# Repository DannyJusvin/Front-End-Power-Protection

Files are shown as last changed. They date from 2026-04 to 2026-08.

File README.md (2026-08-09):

# 🔌 Front-End Power Protection System

### Discrete 12V DC Safeguard with Soft-Start Logic

---

## 📌 Overview

This project presents a **discrete front-end power protection circuit** designed for 12V DC systems. It protects sensitive electronics from unsafe input conditions using a **P-channel MOSFET-based high-side topology**.

The design integrates:

* Over-voltage protection (OVP) with hysteresis
* Reverse polarity protection
* Controlled soft-start to mitigate inrush current

The circuit was designed, simulated, and validated in **LTspice**, and documented with a complete engineering workflow.

---

## 🚀 Design Evolution

The project evolved through three implementation stages:

1. **LTspice — Circuit Design & Verification**
   - Circuit behavior and protection functions were developed and validated through simulation.

2. **KiCad — THT Prototype Schematic**
   - The validated circuit was documented as a through-hole-oriented schematic for the initial implementation.

3. **Altium Designer — SMT PCB Implementation**
   - The design was transitioned to surface-mount components and implemented as a two-layer PCB.
   - Component libraries and footprints were configured, followed by component placement, manual routing, ground-plane implementation, and DRC verification.
   - PCB 3D models were integrated and aligned for board-level 3D inspection and design verification.
   - Gerber, NC Drill, and Pick-and-Place manufacturing outputs were generated.

The electrical functionality was retained during the transition, while the implementation evolved from a simulation/prototype-oriented design toward a more compact, manufacturing-oriented PCB.

---

## 🎯 Key Features

* ⚡ **Over-Voltage Protection (OVP)**

  * Trip: ~13.9 V
  * Release: ~13.3 V (hysteresis ≈ 0.6 V)

* 🔄 **Reverse Polarity Protection**

  * Implemented using a high-current Schottky diode (MBR745)

* ⏱️ **Soft-Start Control**

  * ~10–13 ms controlled ramp
  * Reduces inrush current stress

* ⚡ **Fast Protection Response**

  * ~1.6 µs detection and cutoff (comparator + gate drive)

---

## 🧠 Design Highlights

* Discrete implementation (no integrated protection ICs)
* Demonstrates:

  * Comparator-based decision making
  * Positive feedback (hysteresis)
  * MOSFET gate control dynamics
  * Real-world non-idealities (Zener knee region, MOSFET capacitances)

---

## 🧩 System Architecture

* Input Protection (Schottky diode)
* Power Switching (PMOS – IRF4905)
* Analog Control (LM393 comparator + reference + hysteresis)
* Gate Drive & Soft-Start (PNP + RC network + clamp)

---

## 📊 Performance Summary

| Parameter | Value |
| --- | --- |
| Nominal Input | 12 V |
| OVP Trip | ~13.9 V |
| OVP Release | ~13.3 V |
| Soft-Start Time | ~10–13 ms |
| Response Time | ~1.6 µs |
| Efficiency | ~96% |
| Practical Current | ~2–3 A (continuous, no heatsink) |

---

## 🧪 Simulation & Validation

* LTspice transient simulations
* Tested scenarios:

  * Normal startup
  * Over-voltage event
  * Load variation (10Ω, 2Ω, 1Ω)
  * Reverse polarity

---

## ⚠️ Limitations

* No over-current protection (OCP)
* No under-voltage lockout (UVLO)
* Diode voltage drop reduces efficiency
* Zener-based reference has limited accuracy

---

## 🚀 Future Improvements

* Add current sensing (INA180 / shunt-based OCP)
* Replace Zener with precision reference (TL431)
* Use ideal diode MOSFET for lower loss
* Add UVLO and thermal protection

---

## 📁 Repository Contents

* Project Documentation
* Project Log
* Block Diagram
* BOM — THT and SMT component lists
* LTspice simulation files and waveform results
* KiCad prototype schematic — THT implementation
* Altium Designer schematic and PCB — SMT implementation
* PCB renders and layout images
* Gerber manufacturing files
* NC Drill files
* Pick-and-Place files

---

## 🛠 Tools Used

* LTspice (Simulation)
* KiCad (Schematic)
* Altium (Schematic & PCB Design)
* draw.io (Block Diagram)

---

## 💡 Author Note

This project was developed to deeply understand analog power protection design, including transient behavior, feedback systems, and real-world component limitations, while also gaining hands-on experience with LTspice simulation, KiCad schematic development, Altium Designer PCB design, component libraries, design-rule verification, and manufacturing preparation.

---

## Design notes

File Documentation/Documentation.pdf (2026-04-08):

# FRONT-END POWER PROTECTION SYSTEM

## Discrete 12V DC Safeguard with Soft-Start Logic

### TABLE OF CONTENTS

- Abstract - Problem Statement - Project Overview - Design Objectives - System Architecture - Circuit Operation - Circuit Schematic - Tools & Technologies - Design Calculations & Engineering Decisions - Component Selection & Justification - Bill of Materials (BoM) - Simulation Setup - Performance Analysis - Real-World Consideration - Limitations - Future Improvements - Design Evolution - Conclusion - References

# 1. Abstract

An LTspice-validated 12V DC front-end protection circuit designed to shield sensitive electronics using a discrete P-channel MOSFET topology. The system integrates 13.9V over-voltage protection with hysteresis, reverse polarity safety, and a controlled 10–13 ms soft-start to mitigate inrush current. By avoiding integrated IC solutions, the project demonstrates a deep-dive into the fundamental trade-offs of analog power management, transient response, and circuit stability.

# 2. Problem Statement

Modern 12V electronic systems—including embedded controllers, communication devices, and analog subsystems—typically operate within a narrow voltage range (~11–13.2V). Despite being powered by regulated DC supplies, these systems remain highly vulnerable to several real-world electrical faults:

- Over-Voltage Conditions: Triggered by regulator failure, supply overshoot, or transient spikes

that exceed safe operating limits.

- Reverse Polarity Connection: Accidental incorrect supply connections during installation or

maintenance.

- High Inrush Current: Rapid charging of decoupling capacitors during startup, which stresses

both the power path and the load components.

Even short-duration over-voltage events can exceed the absolute maximum ratings (typically ~15V) of downstream ICs, leading to immediate degradation or permanent failure. Furthermore, while integrated protection ICs (e.g., hot-swap controllers) are available, they often act as "black boxes," abstracting away the underlying analog behaviors and transient responses.

This project addresses the need for a transparent, discrete protection solution that provides robust fault protection while exposing the internal design trade-offs, non-ideal component behaviors, and real-world stability challenges inherent in power electronics.

# 3. Project Overview

This project presents the design and simulation of a 12V DC power protection circuit intended for low-power electronic systems. The circuit acts as a front-end protection module placed between a DC power source and a sensitive load, ensuring safe and controlled power delivery under both normal and fault conditions.

The design integrates multiple protection features into a single discrete implementation:

- Reverse Polarity Protection: Prevents damage from incorrect supply connections.
- Over-Voltage Protection (OVP): Features a cutoff threshold of approximately 13.9V.
- Hysteresis (~0.6V): Ensures stable switching and prevents chatter.
- Soft-Start Control (~10–13ms): Limits inrush current during startup and recovery.
- High-Speed Gate-Drive: Ensures rapid MOSFET turn-off during fault conditions.

The circuit is built using a high-side P-channel MOSFET switching topology, controlled by a comparator-based decision stage and supported by analog feedback networks.

The primary objective of this project is not only functional implementation but also to explore real-world analog design challenges such as non-ideal component behavior, transient response, stability, thermal considerations, and protection trade-offs.

The design was developed and validated entirely through LTspice simulation, with extensive testing under multiple conditions including load variation, over-voltage events, and reverse polarity scenarios. This project demonstrates a practical and engineering-focused approach to power protection, emphasizing architectural reasoning and empirical validation rather than relying on integrated protection IC solutions.

# 4. Design Objectives

The circuit was designed with the following key objectives:

1. Reverse Polarity Protection: Ensure that the circuit and connected load are protected against accidental reversal of supply polarity, preventing component damage.
2. Over-Voltage Protection (OVP): Detect and disconnect the load when the input voltage exceeds a predefined threshold.
- Target cutoff voltage: ≈ 13.9 V
- Purpose: Protect downstream electronics from unsafe voltage levels, particularly those

with ~15 V absolute maximum ratings.

3. Hysteresis Implementation: Introduce a controlled hysteresis band to avoid rapid switching (chatter) near the threshold.
- Target hysteresis band: ≈ 0.6 V
- Result: Ensures a clean transition between ON and OFF states.
4. Soft-Start Control: Gradually ramp up the output voltage during startup and recovery to limit inrush current.
- Target soft-start duration: ≈ 10–13 ms
- Impact: Reduces stress on both the MOSFET and the load; designed to be largely load-

independent for consistent behavior.

5. Fast Protection Response: Ensure rapid system response to fault conditions through a dedicated gate-drive path.
- Electronic response time: ≈ 1.6 µs (includes comparator propagation delay and

MOSFET gate transition).

- Note: Output voltage decay is governed by load and output capacitance rather than

switching delay.

6. Target Operating Conditions:
- Nominal input voltage: 12 V DC
- Intended load current: 2–3 A (continuous, without heatsinking).
- Application: Suitable for low-power regulated 12 V electronic systems.

7. Design Transparency and Learning Focus: Utilize a fully discrete approach (comparator + MOSFET + passive components) instead of integrated solutions to enable deeper understanding of:
- Analog decision-making and feedback behavior.
- Non-ideal effects and power device dynamics.
- Architectural reasoning and iterative improvement.

# 5. System Architecture

The circuit can be understood as a combination of four functional blocks, each responsible for a specific aspect of protection and control:

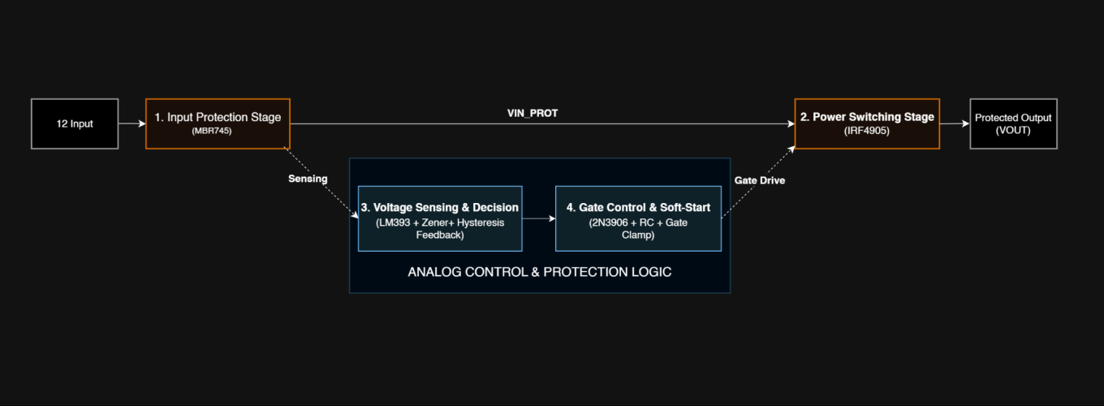
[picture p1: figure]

### 1. Input Protection Stage

Provides reverse polarity protection using a series Schottky diode (MBR745), ensuring that incorrect supply connection does not damage downstream components.

### 2. Power Switching Stage

A high-side P-channel MOSFET (IRF4905) acts as the main power switch.

- ON state: Gate pulled low → conducts power to load.
- OFF state: Gate pulled high (≈ source) → disconnects load.

### 3. Voltage Sensing and Decision Stage

Implemented using an LM393 comparator with:

- Resistive divider (R1, R2 ): Senses VIN_PROT .
- Zener-based reference (~5V region): Provides comparison baseline.
- Hysteresis network (R5): Ensures stable switching.

### 4. Gate Control and Soft-Start Network

Controls MOSFET gate behavior:

- PNP transistor (2N3906): Fast gate pull-up during fault (turn OFF).
- RC network (R9, C3, Rg): Controlled gate discharge (soft-start).
- Zener clamp (15V): Protects MOSFET Vgs from overvoltage.

These blocks operate together to ensure that power is delivered safely under normal conditions, faults are detected quickly, and transitions are controlled to avoid electrical stress.

# 6. Circuit Operation

## 6.1 Normal Operation (Below 13.9 V)

When VIN_PROT is within the safe operating range:

- Voltage Divider Action: The input voltage is scaled down by R1 and R2 .
- Comparator Decision: The scaled voltage (IN−) is lower than the reference (IN+).
- Comparator Output: LM393 output remains HIGH (via pull-up resistor).
- PNP Transistor State: High comparator output keeps the PNP transistor OFF.
- MOSFET Gate Behavior: Gate is pulled down gradually through the RC network (R8 + R9 + C3).
- MOSFET Conduction: Vgs becomes sufficiently negative → MOSFET turns ON.

- Output: VOUT ≈ VIN_PROT with minimal voltage drop.

Result: The system operates normally and supplies power to the load.

## 6.2 Startup (Soft-Start Behavior)

During initial power application:

1. Gate Initial Condition: The MOSFET gate is initially near source potential (OFF state).
2. RC-Controlled Discharge: The gate discharges gradually through R8 and R9 while C3 controls the rate.
3. MOSFET Transition: As Vgs becomes more negative, the MOSFET enters its linear region.
4. Controlled Output Rise: VOUT increases gradually instead of stepping abruptly.
5. Miller Effect Influence: The MOSFET’s internal capacitances (especially Crss ) further smooth the transition.

Result: A controlled output ramp (~10–13 ms) that limits inrush current.

## 6.3 Over-Voltage Detection (≈13.9 V)

When VIN_PROT rises:

1. Divider Output Increases: The sensed voltage at IN− increases proportionally.
2. Threshold Crossing: At ≈13.9 V, IN− exceeds the reference voltage (IN+).
3. Comparator Switching: The LM393 output transitions from HIGH to LOW.
4. Propagation Delay: This transition occurs within ~1.3–1.6 µs from threshold crossing.

Result: Fault condition is detected rapidly.

## 6.4 Cutoff Action (Fast Turn-Off)

Once the comparator output goes LOW:

1. PNP Activation: The LOW output drives the PNP transistor ON.
2. Gate Pull-Up: The transistor quickly pulls the MOSFET gate toward VIN_PROT .
3. Vgs Reduction: Vgs approaches 0 V → MOSFET turns OFF.
4. Load Disconnection: Current flow to the load is interrupted.

### 5. Output Behavior: VOUT decays gradually due to load resistance and output capacitance

(Cload).

Important Note: The electrical switching (MOSFET turn-off) occurs in microseconds, but the output voltage fall is governed by load and capacitance (soft-stop effect).

## 6.5 Recovery (Hysteresis Action ≈13.3 V)

As VIN_PROT decreases:

1. Hysteresis Effect: Due to positive feedback (R5), the release threshold is lower (~13.3 V).
2. Comparator Reset: When VIN_PROT falls below this level, comparator output returns HIGH.
3. PNP Turns OFF: Gate pull-up path is removed.
4. Gate Discharge Resumes: Gate voltage decreases gradually via RC network.
5. MOSFET Turns ON: Soft-start sequence repeats.

Result: Stable recovery without oscillation or chatter.

# 7. Circuit Schematic

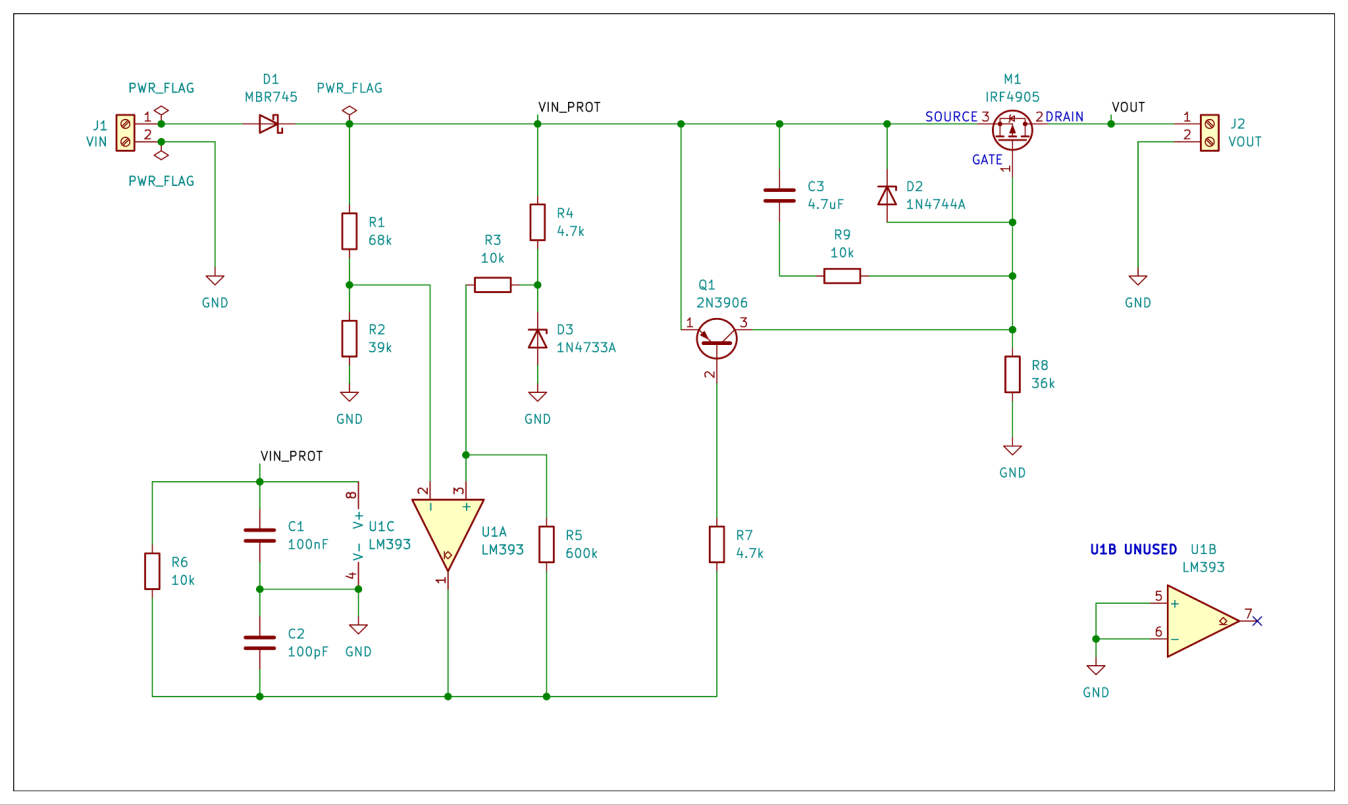
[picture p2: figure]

# 8. Tools & Technologies

The project was developed and validated using the following tools:

- LTspice 24: Used for circuit simulation, transient analysis, and validation of dynamic behavior under different operating conditions.
- KiCad 9.0: Used for schematic capture and creation of a clean, professional circuit diagram.
- draw.io: Used to create the system-level block diagram for visual representation of circuit architecture.

These tools enabled iterative design, debugging, and performance evaluation without requiring physical hardware implementation.

# 9. Design Calculations & Engineering Decisions

## 9.1 Voltage Divider & Trip Threshold

The over-voltage threshold is determined using a resistive voltage divider formed by R1 and R2.

- R1: 68 kΩ (upper resistor)
- R2: 39 kΩ (lower resistor)

The divider scales VIN_PROT to a lower voltage suitable for comparison with the reference. The divider output voltage is calculated as:

Substituting the values:

At the intended trip point:

## 9.2 Reference Voltage (Zener Behavior)

The reference voltage is generated using D3 (1N4733A, nominal 5.1 V Zener) with series bias resistor R4.

- R4: 4.7 kΩ (bias resistor)
- D3: 1N4733A (5.1 V nominal)

However, the Zener voltage depends on current.

At VIN_PROT ≈ 13.9 V :

Note: At this low current, the Zener operates in the knee region, resulting in a lower actual voltage (VZ

≈ 4.8 - 4.9 V) rather than the nominal 5.1 V. This explains why the real-world trip voltage differs

slightly from ideal calculations.

## 9.3 Comparator Threshold Matching

The comparator switches when V(IN-) ≈ V(IN+). Based on the measured Zener behavior:

The deviation to the measured ~13.9 V is attributed to component tolerances (Zener and resistors), comparator input offset, and the loading effect of the hysteresis network.

## 9.4 Hysteresis Design (≈0.6 V)

Hysteresis is implemented using R5 (600 kΩ), feeding the output back to the non-inverting input. This creates two distinct thresholds:

- Trip (OFF):
- Release (ON):
- Hysteresis Width:

Purpose: Prevents oscillation (chatter) near the threshold, ensures clean switching, and improves system noise immunity.

Note: The exact hysteresis band is influenced by R5 value, divider impedance and comparator output swing. The final value was tuned based on simulation and validation behaviour.

## 9.5 Soft-Start Timing (RC Network)

Soft-start is controlled by the RC network formed by R9 and C3.

- R9: 10 kΩ
- C3: 4.7 µF

The theoretical time constant is:

Engineering Insight: The observed soft-start (~10–13 ms) is shorter than because the MOSFET begins conducting as soon as Vgs reaches the threshold voltage (Vgs(th) ) rather than waiting for the

full RC settling time. Device physics, including the nonlinear gate capacitances (Cgs ,Crss ) & Miller

plateau, also influences this ramp.

## 9.6 Gate Drive Strategy (Fast Turn-Off)

A PNP transistor (Q1, 2N3906) is used to rapidly pull the MOSFET gate to VIN_PROT during faults.

1. Fault Detected: Comparator output goes LOW.
2. Q1 Activation: Q1 turns ON via base resistor R7 (4.7 kΩ).
3. Rapid Cutoff: Gate is pulled high quickly, resulting in Vgs → 0, forcing the MOSFET OFF.

This dual-path design allows for a fast protection response (~1.6 µs) while maintaining a controlled startup via the RC network.

## 9.7 Gate Protection (Vgs Clamp)

The MOSFET gate is protected by D2 (1N4744A, 15 V Zener).

- Function: Limits maximum negative Vgs to 15 V.
- Safety: Ensures|Vgs|remains below the 20 V absolute maximum limit of the IRF4905.
- Normal State: Vgs ≈ −10 V(within safe limits); the clamp activates only under abnormal conditions.

# 10. Component Selection & Justification

The component selection for this design was based on availability, electrical characteristics, and suitability for discrete analog implementation. Each component was chosen to balance performance, simplicity, and real-world behavior.

### 1. MOSFET (M1 – IRF4905)

A P-channel power MOSFET (IRF4905) is used for high-side switching.

Reasons for selection:

- Low RDS (on) (~20 mΩ) for minimal conduction loss.
- High current capability to support >10 A transient loads.
- TO-220 package for good thermal performance.
- Specifically suited for 12 V systems.

Trade-offs:

- Higher gate charge affects switching speed.
- Requires precise gate control to achieve the desired soft-start ramp.

### 2. Schottky Diode (D1 – MBR745)

Used for reverse polarity protection at the input stage.

Reasons for selection:

- High current rating (7.5 A).
- Fast switching characteristics.
- Low forward voltage (typically 0.4–0.5 V).

Trade-offs:

- Voltage drop reduces overall efficiency (observed ~0.3–0.4 V loss).
- Thermal limitation makes this the primary current bottleneck of the module.

### 3. Comparator (U1 – LM393)

Used for voltage detection and high-speed decision-making.

Reasons for selection:

- Open-collector output allows for flexible interfacing with the gate-drive stage.
- Wide supply voltage range.
- Low cost and high availability.
- Proven reliability for analog threshold detection.

Design consideration:

- Requires an external pull-up resistor (R6).
- Requires compensation (C2) to maintain loop stability.

### 4. Zener Diodes

- D3 (1N4733A – 5.1 V): Used for stable reference generation.
- D2 (1N4744A – 15 V): Used for MOSFET gate-source protection.

Reasons:

- Simple and low-cost alternative to active voltage references.
- Provides adequate accuracy for the protection threshold.
- Gate clamp ensures long-term MOSFET reliability.

Trade-offs:

- Zener voltage varies with bias current (as noted in Section 8.2).
- Less precise than a dedicated TL431 or reference IC.

### 5. PNP Transistor (Q1 – 2N3906)

Used for the fast gate pull-up path during fault conditions.

Reasons:

- Simple, robust implementation for high-speed switching.
- Fast response time to ensure the MOSFET reaches cutoff in microseconds.
- Standard, readily available component.

### 6. Passive Components

Resistors:

- R1, R2: Precision voltage divider for sensing .
- R3: Reference bias (Rref).
- R4: Zener bias resistor (Rz).
- R5: Hysteresis control loop.
- R6: Comparator output pull-up.
- R7: Base current limiting for Q1.
- R8: Gate pull-down resistor.
- R9: Soft-start timing control.

Capacitors:

- C1 (100 nF): Input supply decoupling.
- C2 (100 pF): Comparator stability and noise filtering.
- C3 (4.7 µF): Controls the RC-based soft-start duration.

The design intentionally utilizes discrete components rather than integrated "black-box" solutions to expose internal behavior and the fundamental trade-offs involved in power electronics design.

# 11. Bill of Materials (BoM)

Ref | Component | Value / Part No. | Description
M1 | PMOS | IRF4905 | High-side power MOSFET
Q1 | PNP BJT | 2N3906 | Gate pull-up (fast turn-off)
U1 | Comparator | LM393 | Dual comparator (single used)
D1 | Schottky Diode | MBR745 | Reverse polarity protection
D2 | Zener Diode | 1N4744A (15 V) | Gate-source protection
D3 | Zener Diode | 1N4733A (5.1 V) | Reference voltage
R1 | Resistor | 68 kΩ | Voltage divider (Rtop)
R2 | Resistor | 39 kΩ | Voltage divider (Rbottom)
R3 | Resistor | 10 kΩ | Reference bias (Rref)
R4 | Resistor | 4.7 kΩ | Zener bias (Rz)
R5 | Resistor | 600 kΩ | Hysteresis (Rhys)
R6 | Resistor | 10 kΩ | Comparator pull-up
R7 | Resistor | 4.7 kΩ | Base resistor (Q1)
R8 | Resistor | 36 kΩ | Gate pull-down
R9 | Resistor | 10 kΩ | Soft-start control
C1 | Capacitor | 100 nF | Supply decoupling
C2 | Capacitor | 100 pF | Comparator compensation (Ccomp)
C3 | Capacitor | 4.7 µF | Soft-start timing (Cg)
J1 | Connector | Screw Terminal | Input (VIN)
J2 | Connector | Screw Terminal | Output (VOUT)

# 12. Simulation Setup

The circuit was validated using LTspice transient simulations to ensure stability and reliability across a range of operating environments

### 1. Input Source Configuration

To evaluate the circuit under dynamic conditions, a Piecewise Linear (PWL) voltage source was utilized. This allowed for a precise, scripted sequence of events within a single 500 ms simulation window:

- The Command : PWL(0 0 50m 12 200m 12 350m 15 500m 12)
- The Sequence :
- 0–50 ms: Linear ramp from 0 V to 12 V (Testing Soft-Start).
- 50–200 ms: Stable 12 V nominal operation.
- 200–350 ms: Linear rise to 15 V (Testing Over-Voltage Cutoff).
- 350–500 ms: Return to 12 V (Testing Fault Recovery and Auto-Restart).

Stress Testing Variations: Beyond the standard profile, modified PWL commands and specific .step directives were used to simulate rapid transients, high-frequency supply noise, and extreme load-switching events to ensure the design's robustness.

### 2. Transient Analysis Parameters

- Command : .tran 0 500m
- Step Size : A maximum timestep of 1 ns was enforced during critical threshold crossings to accurately capture the microsecond-scale propagation delays (Tdetect & Texec ).

### 3. Load Conditions

Multiple resistive loads were simulated to evaluate the circuit's performance under varying current demands:

- 10 Ω: Light load (nominal operation).
- 2 Ω: Moderate load (thermal stress testing).
- 1 Ω: Heavy/Transient load (SOA and peak power verification).

The setup was specifically designed to replicate realistic operating and fault conditions, ensuring the design margins are sufficient for physical hardware implementation.

# 13. Performance Analysis

## 13.1 Voltage Behavior

At nominal operation:

- VIN: 12 V
- VIN_PROT: ≈ 11.6–11.7 V
- VOUT: ≈ 11.57 V

Voltage drop sources:

- D1 (Schottky diode): ~0.3–0.4 V drop.
- M1 (MOSFET): Negligible drop (~20–30 mV).

Overall efficiency:

## 13.2 Soft-Start Behavior

Observed soft-start:

- Duration: ≈ 10–13 ms
- Ramp Profile: Controlled linear-to-exponential rise of VOUT .
- Impact: Effectively limits inrush current during startup and fault recovery.

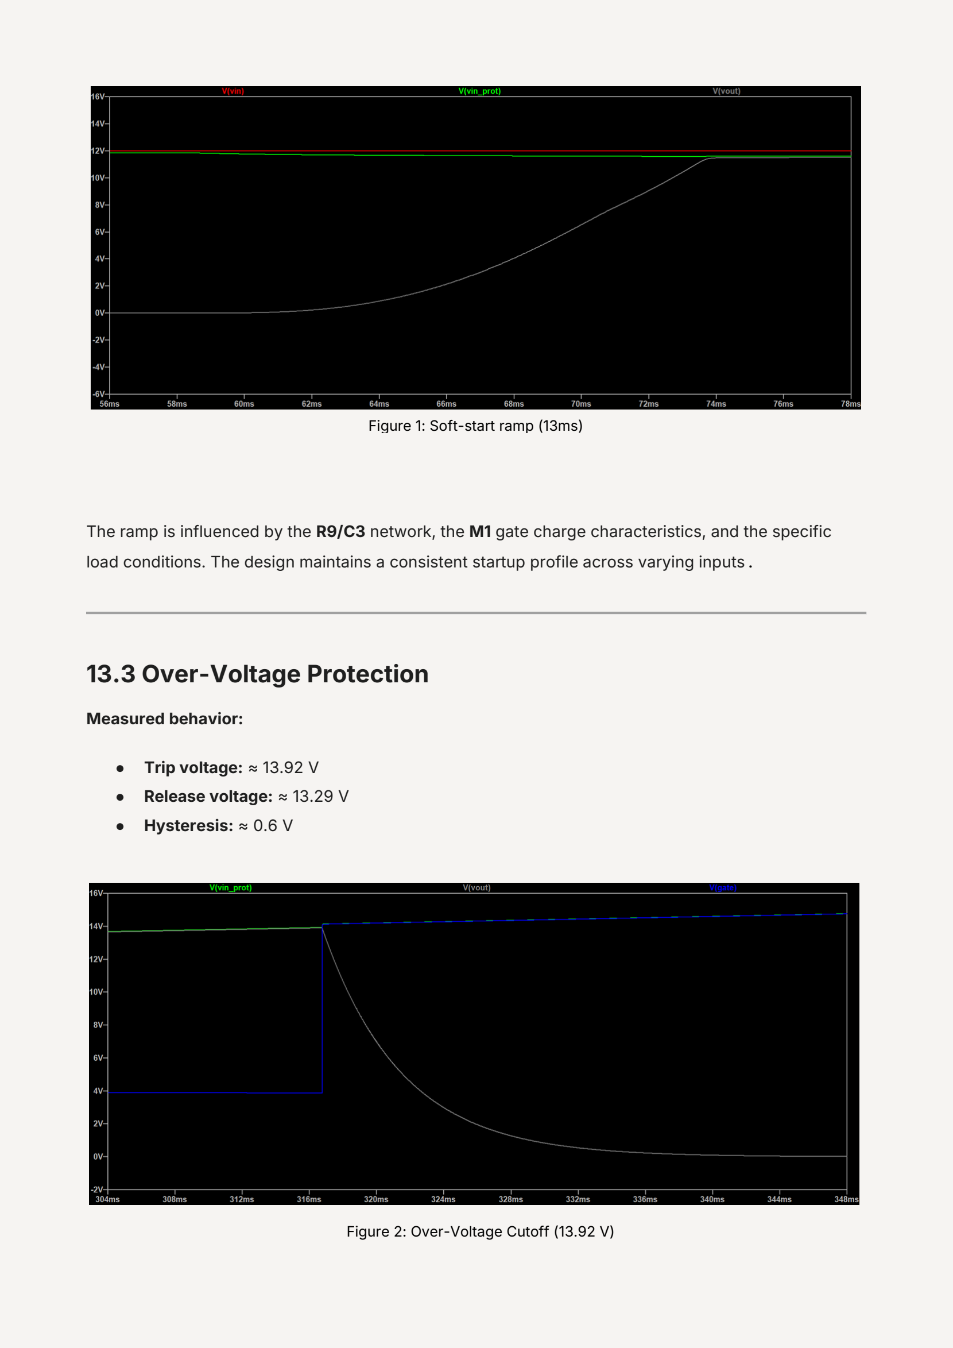
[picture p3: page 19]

The ramp is influenced by the R9/C3 network, the M1 gate charge characteristics, and the specific load conditions. The design maintains a consistent startup profile across varying inputs.

## 13.3 Over-Voltage Protection

Measured behavior:

- Trip voltage: ≈ 13.92 V
- Release voltage: ≈ 13.29 V
- Hysteresis: ≈ 0.6 V

Figure 1: Soft-start ramp (13ms)

Figure 2: Over-Voltage Cutoff (13.92 V)

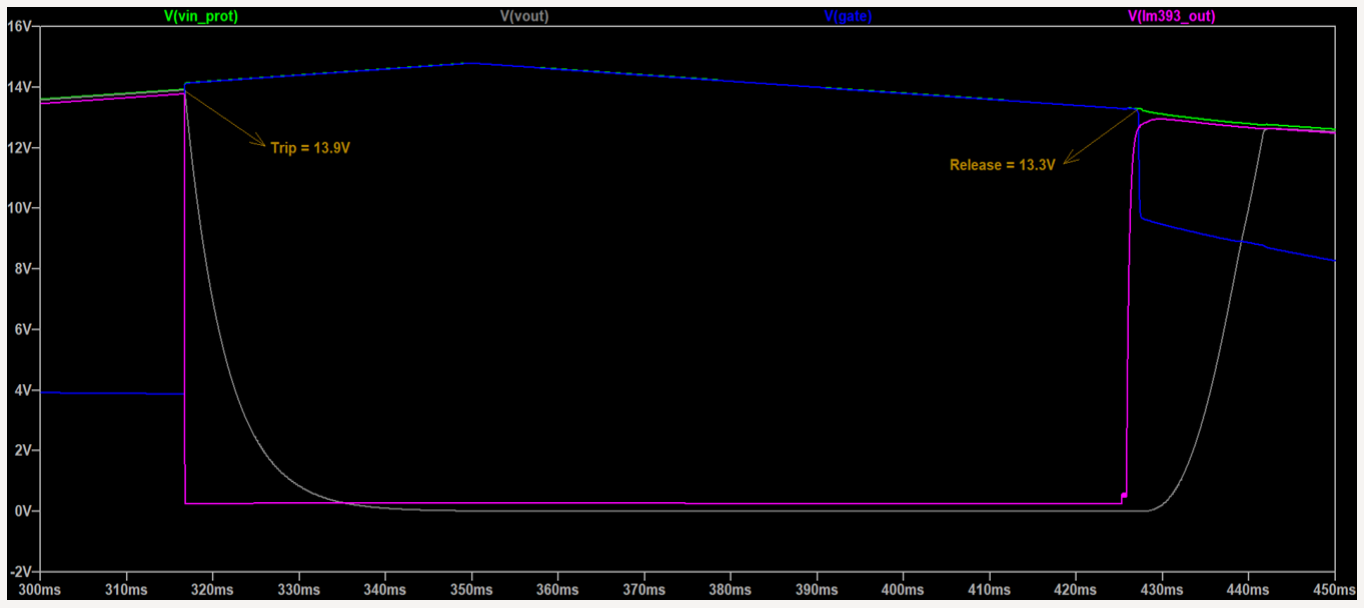
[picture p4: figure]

The comparator output transitions within ~1.6 µs after the threshold is crossed. The MOSFET is turned OFF rapidly via the Q1 (PNP) path, while the output voltage decays gradually based on the connected load and output capacitance.

## 13.4 Load Testing

The circuit was validated under multiple load conditions to ensure stability:

1. 10 Ω Load: Current ≈ 1.3–1.4 A. Stable operation with minimal voltage drop.
2. 2 Ω Load: Current ≈ 6–7 A. Stable switching behavior with increased thermal stress on D1.
3. 1 Ω Load: Current ≈ 12–13 A (transient). Observed significant power spikes in M1, though remaining within the Safe Operating Area (SOA) for short durations.

## 13.5 Power Dissipation

Power dissipation was analyzed to ensure component reliability during both normal operation and fault conditions.

### Transient events:

- MOSFET peak power: Evaluated at the moment of over-voltage cutoff across varying loads:

- 10 Ω Load (~1.3 A): ≈ 150 W
- 2 Ω Load (~6–7 A): ≈ 160–170 W
- 1 Ω Load (~12–13 A): ≈ 190 W
- Schottky Diode: Experiences significant peak power under low-resistance loads before cutoff.
- Safety: These are microsecond-scale pulses that fall safely within the device Safe Operating

Area (SOA).

### Steady-state losses:

- MOSFET: Extremely low due to low RDS (on) .
- Diode: Acts as the dominant loss element (P = Vf × I ) and the primary thermal bottleneck.

## 13.6 Response Time

### Summary:

- Comparator switching: ~1.34 µs.
- Gate transition: ~0.28 µs.
- Total protection response: ~1.63 µs.

### Timing Breakdown:

To better understand the system response, the total delay can be divided into three stages:

### 1. Detection latency (Tdetect ): 1.344 µs

Time from threshold crossing to comparator output transition; consistent with device propagation delay.

### 2. Execution latency (Texec): 0.284 µs

Time required for the driver stage to discharge the MOSFET gate and initiate turn-off.

### 3. Total reaction time: 1.628 µs

Overall delay from over-voltage detection to the start of load disconnection.

Note: While MOSFET turn-off occurs within ~2 µs, the decay of VOUT depends on load resistance and output capacitance.

## 13.7 Protection Validation

Reverse polarity test:

- VIN_PROT: ≈ 0 V.
- VOUT: ≈ 0 V.
- Result: No conduction occurs; the circuit and load are fully protected.

Over-voltage spike test:

- Detection: System correctly identifies the fault.
- Action: M1 turns OFF immediately.
- Recovery: Output recovers cleanly and performs a soft-start once the fault is removed.

The circuit demonstrates reliable, repeatable protection under all simulated fault conditions.

# 14. Real-World Consideration

While the circuit has been validated through simulation, several real-world factors can influence its performance. These variables should be considered for physical PCB implementation and environmental testing.

### 1. PCB Trace Resistance

In a physical implementation, copper traces introduce parasitic resistance, especially in high-current paths. This can lead to:

- Voltage Drop: Additional millivolts lost across the board.
- Power Dissipation: I²R losses within the traces themselves.
- Localized Heating: Increased thermal stress on the PCB substrate near the diode and MOSFET.

### 2. Connector and Contact Resistance

Screw terminals and connectors introduce small resistances (typically 10–50 mΩ) that become significant at higher currents. These contacts can act as heat sources if not properly rated for the 10+ A transients discussed in the load testing section.

### 3. Temperature Effects

Component behavior varies with ambient temperature and self-heating:

- MOSFET RDS (on) : Increases significantly with temperature, potentially doubling at high junction temperatures.
- Diode Forward Voltage: Decreases as temperature rises, which can slightly shift efficiency.
- Zener Voltage: Drifts with temperature changes (positive or negative depending on the Zener voltage).
- Comparator Offset: Input offset voltage varies, which may slightly shift the trip threshold.

### 4. Zener Tolerance and Operating Region

The reference Zener (D3) operates in the "knee region" (~1–2 mA) rather than its rated test current (≈49 mA). This results in:

- Lower Effective Voltage: Observed ~4.8–4.9 V instead of the nominal 5.1 V.
- Increased Variation: The reference is more sensitive to input voltage fluctuations in this region.

### 5. Tolerance Stack-Up

The actual trip voltage in a production run will vary due to the combined tolerances of:

- Resistors: Typically ±1% or ±5%.
- Zener Diodes: Nominal vs. actual breakdown.
- Comparator Offset: Internal manufacturer variations.

These factors together define the "design margin" required to ensure the circuit triggers reliably within a safe window.

### 6. MOSFET Gate Behavior

Real-world MOSFET switching is more complex than simple RC timing due to:

- Gate Charge (Qg ): Total energy required to flip the switch.
- Miller Capacitance (Crss ): Influences the "plateau" in the gate voltage waveform.
- Nonlinear Capacitances: Cgs and Cds vary with applied voltage, affecting soft-start and switching dynamics.

### 7. Supply Noise and Transients

Practical environments (especially automotive or industrial) include switching noise and load-induced transients. The inclusion of C1 (decoupling capacitor) is critical for filtering high-frequency noise and preventing "chatter" or false tripping of the comparator.

Conclusion: The simulated behavior represents an idealized scenario. A robust implementation requires accounting for these physical variations to ensure long-term reliability.

# 15. Limitations

Despite its functionality, the circuit has several inherent limitations that should be noted for specific applications:

### 1. No Over-Current Protection (OCP)

The circuit does not actively sense or limit the output current. In a fault condition, such as a short circuit, the current is limited only by the source impedance and the saturation characteristics of the MOSFET.

### 2. No Under-Voltage Lockout (UVLO)

The current design focus is strictly on over-voltage and reverse polarity. It does not disconnect the load during under-voltage conditions, which could be a concern for battery-sensitive applications.

### 3. Current Capability Limited by Diode (D1)

While the MOSFET is rated for high currents, the D1 Schottky diode effectively limits the continuous current to approximately 3 A without an external heatsink due to thermal dissipation.

### 4. Voltage Drop

The inclusion of the series protection diode introduces a forward voltage drop (typically 0.3–0.4 V). This reduces the overall system efficiency and the available voltage delivered to the load.

### 5. Limited Threshold Accuracy

The use of a simple Zener diode as a voltage reference introduces minor inaccuracies due to:

- Voltage Variation: Dependency on the bias current through R4.
- Temperature Dependence: Thermal drift affecting the Zener breakdown voltage.

### 6. Not Suitable for Automotive Systems

The current OVP threshold (~13.9 V) is lower than standard automotive charging voltages, which typically range from 13.5 V to 14.7 V. Using this circuit in a modern vehicle would result in frequent unintended cutoffs.

### 7. No Short-Circuit Protection

The circuit lacks a fast-acting current shut-off mechanism. High current spikes can occur under short-circuit conditions, potentially stressing the components before external fuses or source limits engage.

Conclusion: These limitations highlight clear areas for refinement in future iterations of the design.

# 16. Future Improvements

To evolve the design from a discrete prototype to a robust, professional-grade protection module, the following enhancements are proposed:

### 1. Over-Current Protection (OCP)

- Sense Resistor: Integrate a low-side or high-side shunt resistor to monitor current flow.
- Amplification: Utilize a dedicated current-sense amplifier (e.g., INA180) for precision.
- Logic: Implement a latching cutoff or active current limiting to protect the MOSFET and load during short circuits.

### 2. Crowbar Protection

- Mechanism: Add an SCR-based crowbar circuit at the output.
- Function: Provides a "hard" shutdown by blowing an input fuse during severe over-voltage events, serving as a redundant safety layer if the MOSFET fails to open.

### 3. Under-Voltage Lockout (UVLO)

- Logic: Add a second comparator stage to monitor the lower voltage bound.
- Benefit: Prevents operation under unsafe low-voltage conditions, which is critical for protecting lead-acid or lithium batteries from deep discharge.

### 4. Precision Voltage Reference

- Upgrade: Replace the Zener diode (D3) with a precision shunt regulator like the TL431.
- Benefit: Significantly improves threshold accuracy, reduces temperature drift, and eliminates the "knee region" inconsistencies observed in the current design.

### 5. "Ideal Diode" Reverse Protection

- Upgrade: Replace the Schottky diode (D1) with an N-channel or P-channel MOSFET-based "ideal diode" controller.
- Benefit: Reduces the forward voltage drop from ~400 mV to negligible levels (I × RDS (on)),

drastically increasing efficiency and reducing heat.

### 6. Thermal Management

- Physical: Add dedicated heatsinking to the TO-220 packages.
- PCB Design: Optimize copper pour areas to act as "thermal vias" and heat spreaders for surface-mount components.

### 7. PCB Layout Optimization

- Trace Width: Utilize heavy copper (~2.8 mils) and wide traces for high-current paths.
- Kelvin Sensing: Implement Kelvin connections for the voltage divider to ensure the comparator senses the true input voltage, independent of high-current trace drops.
- Grounding: Separate power ground from signal ground (Star Grounding) to prevent switching noise from affecting the comparator's reference.

### 8. Transient Protection

- Component: Add a Transient Voltage Suppressor (TVS) diode at the input.
- Benefit: Protects the internal circuitry against high-voltage surges and "load dump" transients common in automotive and industrial environments.

Conclusion: These improvements can significantly enhance robustness and performance.

# 17. Design Evolution

This project underwent multiple iterations and refinements during development. The transition from a theoretical concept to a validated simulation required addressing several non-ideal behaviors inherent in analog components.

### 1. Hysteresis Implementation

Challenge: Initial design attempts placed the feedback network on the inverting input, which led to significant instability and high-frequency oscillation near the trip threshold.

Learning Point: Transitioning to a positive feedback topology on the non-inverting input (via R5) successfully implemented hysteresis. This resulted in the stable, clean switching behavior required for a protection circuit.

### 2. Zener Behavior Realization

Challenge: The reference Zener (D3) was initially assumed to maintain a fixed 5.1 V across all operating conditions.

Learning Point: Simulation revealed that at the low bias currents used (~1–2 mA), the diode operates in the "knee region," yielding a lower voltage of ~4.8–4.9 V. This discovery necessitated a recalculation of the voltage divider (R1, R2) to maintain the desired 13.9 V trip point.

### 3. Ideal vs. Real MOSFET Model

Challenge: Initial simulations using idealized MOSFET models failed to capture the nuances of the turn-on and turn-off phases.

Learning Point: Replacing the ideal component with a high-fidelity IRF4905 model revealed the significant influence of gate charge (Qg ) and Miller capacitance (Crss ). This change provided a

much more accurate representation of the soft-start ramp and switching energy.

### 4. Soft-Start Design Refinement

Challenge: Reaching a consistent ~10 ms startup time was difficult because the MOSFET threshold voltage (Vgs(th) ) varies between units and models.

Learning Point: The RC network (R9, C3) required iterative tuning. By understanding that the MOSFET begins conducting well before the capacitor is fully charged, the values were optimized to provide a smooth, repeatable power-up sequence.

### 5. Simulation Convergence Issues

Challenge: The complex interaction between the high-gain comparator, the positive feedback loop, and the heavy switching of the P-MOSFET occasionally caused the simulation engine to stall or produce convergence errors.

Learning Point: This required fine-tuning simulation parameters and circuit topology (such as adding the C2 compensation capacitor) to ensure the software could accurately model the rapid transitions without mathematical instability.

### 6. Reverse Polarity Protection Integration

Challenge: Adding D1 (Schottky diode) provided essential protection but introduced a series voltage drop that affected efficiency.

Learning Point: This highlighted the fundamental trade-off in analog design: adding protection features often comes at the cost of slight power loss and increased thermal management requirements.

Conclusion: These iterations emphasize that successful analog design depends on moving beyond "ideal" calculations and accounting for the non-linear, non-ideal behaviors of real-world silicon.

# 18. Conclusion

This project demonstrates the design and validation of a discrete 12 V power protection circuit incorporating multiple protective features within a simple architecture. By utilizing standard analog components, the system provides a robust solution for safeguarding sensitive electronics from common power-line faults.

The circuit successfully achieves:

- Reverse polarity protection via a high-current Schottky diode.
- Over-voltage cutoff at ≈13.9 V with a stable 0.6 V hysteresis band.
- Controlled soft-start with a 10–13 ms ramp to mitigate inrush current.
- Fast protection response of ≈1.6 µs to ensure rapid disconnection during spikes.

The design highlights key analog engineering concepts, including feedback behavior, device non-idealities, transient response, and trade-offs in component selection. Through iterative refinement and simulation-based validation, the project evolved from a theoretical concept into a well-characterized and functional protection system.

While the current implementation has inherent limitations—specifically regarding thermal bottlenecks and precision—it provides a strong foundation for future enhancements. This project serves as a practical demonstration of power electronics design principles and the importance of bridging the gap between ideal models and real-world component behavior.

# 19. References

GitHub: https://github.com/DannyJusvin/Front-End-Power-Protection

Simulation Waveform: Simulation Waveform.pdf (https://github.com/DannyJusvin/Front-End-Power-Protection/blob/main/Simulation%20Waveform.pdf)

Circuit Schematic: Protection System Schematics.pdf (https://github.com/DannyJusvin/Front-End-Power-Protection/blob/main/Protection%20System%20Schematics.pdf)

Project Logs: Project Logs.pdf (https://github.com/DannyJusvin/Front-End-Power-Protection/blob/main/Project%20Logs.pdf)

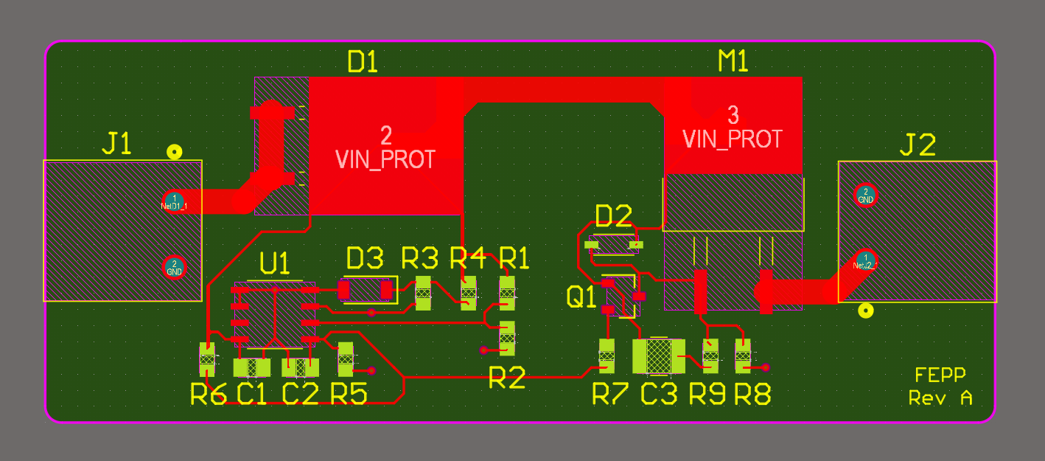
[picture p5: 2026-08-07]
Altium PCB (SMT)/PCB_Top.png

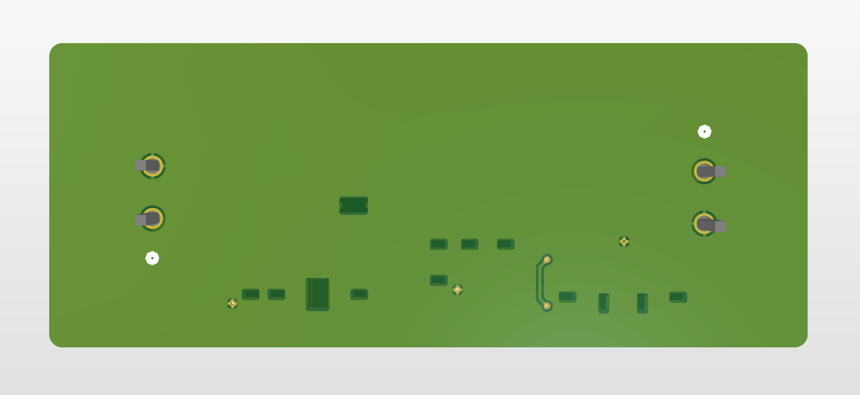
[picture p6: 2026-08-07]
Altium PCB (SMT)/PCB_3D_Back.png

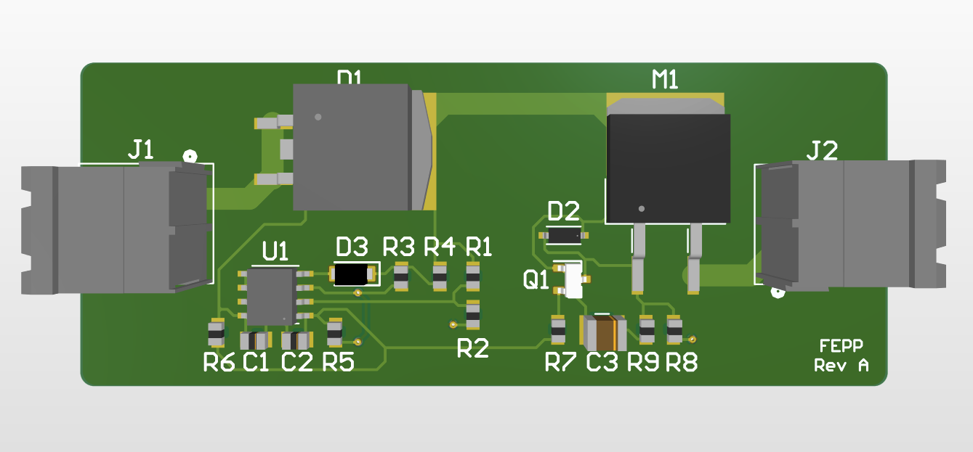
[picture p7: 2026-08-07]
Altium PCB (SMT)/PCB_3D_Front.png

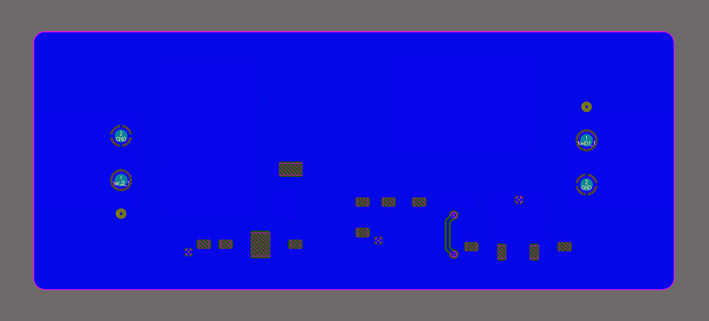
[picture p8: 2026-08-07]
Altium PCB (SMT)/PCB_Bottom.png

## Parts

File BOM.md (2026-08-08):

## Bill of Materials (BOM)

**DC-12V Protection System** — component mapping from the original THT design (LTspice/KiCad) to the current SMT design (Altium, PCB layout).

| Ref | Type | Value | THT Part (Package) | SMT Part / MPN (Package) | Description |
|-----|---|---|---|---|---|
| M1 | PMOS | — | IRF4905 (TO-220AB) | IRF4905STRLPBF (D2PAK) | High-side power MOSFET |
| Q1 | PNP BJT | — | 2N3906 (TO-92) | MMBT3906 (SOT-23) | Gate pull-up (fast turn-off) |
| U1 | Comparator | — | LM393 (PDIP-8) | LM393D (SOIC-8) | Dual comparator (2nd half unused) |
| D1 | Schottky Diode | — | MBR745 (TO-220AC) | MBRB745 (SMB / DO-214AA) | Reverse polarity protection |
| D2 | Zener Diode | 15 V | 1N4744A (DO-41) | MMSZ5245B (SOD-123) | Gate-source protection |
| D3 | Zener Diode | 5.1 V | 1N4733A (DO-41) | MM1Z4733A (SOD-123FL) | Reference voltage |
| R1 | Resistor | 22 kΩ | Generic axial (THT) | RC0805FR-0722KL (0805) | Voltage divider (upper) |
| R2 | Resistor | 13 kΩ | Generic axial (THT) | RC0805FR-0713KL (0805) | Voltage divider (lower) |
| R3 | Resistor | 10 kΩ | Generic axial (THT) | RC0805FR-0710KL (0805) | Reference bias (Rref) |
| R4 | Resistor | 1 kΩ | Generic axial (THT) | RC0805FR-071KL (0805) | Zener bias (Rz) |
| R5 | Resistor | 600 kΩ* | Generic axial (THT) | RC0805FR-07590KL* (0805) | Hysteresis |
| R6 | Resistor | 10 kΩ | Generic axial (THT) | RC0805FR-0710KL (0805) | Comparator pull-up |
| R7 | Resistor | 4.7 kΩ | Generic axial (THT) | RC0805FR-074K7L (0805) | Base resistor (Q1) |
| R8 | Resistor | 36 kΩ | Generic axial (THT) | RC0805FR-0736KL (0805) | Gate pull-down |
| R9 | Resistor | 10 kΩ | Generic axial (THT) | RC0805FR-0710KL (0805) | Soft-start control |
| C1 | Capacitor | 100 nF | Generic ceramic (THT) | 08053C104KAT2A (0805) | Supply decoupling |
| C2 | Capacitor | 100 pF | Generic ceramic (THT) | TBD (0805) | Comparator compensation |
| C3 | Capacitor | 4.7 µF | Generic (THT) | CC1210KKX7R9BB475 (1210) | Soft-start timing |
| J1 | Connector | — | Screw Terminal | 282814-2 (THT, 2-pos) | Input (VIN) |
| J2 | Connector | — | Screw Terminal | 282814-2 (THT, 2-pos) | Output (VOUT) |

\* R5's nominal 600 kΩ is not a stocked standard value in Yageo's RC0805FR-07 (E96) series. The nearest real, in-stock part is 590 kΩ (~1.7% off nominal), used here as the practical substitute.

Note: J1/J2 remain THT screw terminals in the SMT revision — all other components were converted to SMD.

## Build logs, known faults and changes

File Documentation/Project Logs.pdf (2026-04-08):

# Project Logs

# Week 1: Problem Definition & Concept Exploration

- Identified the need for a front-end protection circuit for 12V systems
- Studied over-voltage protection, reverse polarity protection, and soft-start techniques
- Evaluated discrete vs integrated approaches

# Week 2: Initial Circuit Design

- Designed comparator-based over-voltage detection using LM393
- Implemented voltage divider and Zener reference
- Established initial trip threshold concept

# Week 3: Hysteresis & Stability Debugging

- Implemented hysteresis using feedback resistor
- Identified incorrect feedback topology causing instability
- Corrected to positive feedback (IN+) and verified stable switching

# Week 4: Power Stage Integration

- Integrated high-side PMOS (IRF4905)
- Transitioned from ideal MOSFET to real model
- Observed effects of gate charge, Miller capacitance, and threshold behavior

# Week 5: Soft-Start & Protection Refinement

- Designed RC-based soft-start network
- Tuned values to achieve ~10–13 ms ramp
- Added gate protection (15V Zener clamp)
- Integrated reverse polarity protection (MBR745)

# Week 6: Testing, Validation & Documentation

- Performed load testing (10Ω, 2Ω, 1Ω)
- Verified OVP threshold (~13.9V) and hysteresis (~0.6V)
- Evaluated transient response and power dissipation
- Finalized README.md, BOM, schematic, block diagram, and documentation

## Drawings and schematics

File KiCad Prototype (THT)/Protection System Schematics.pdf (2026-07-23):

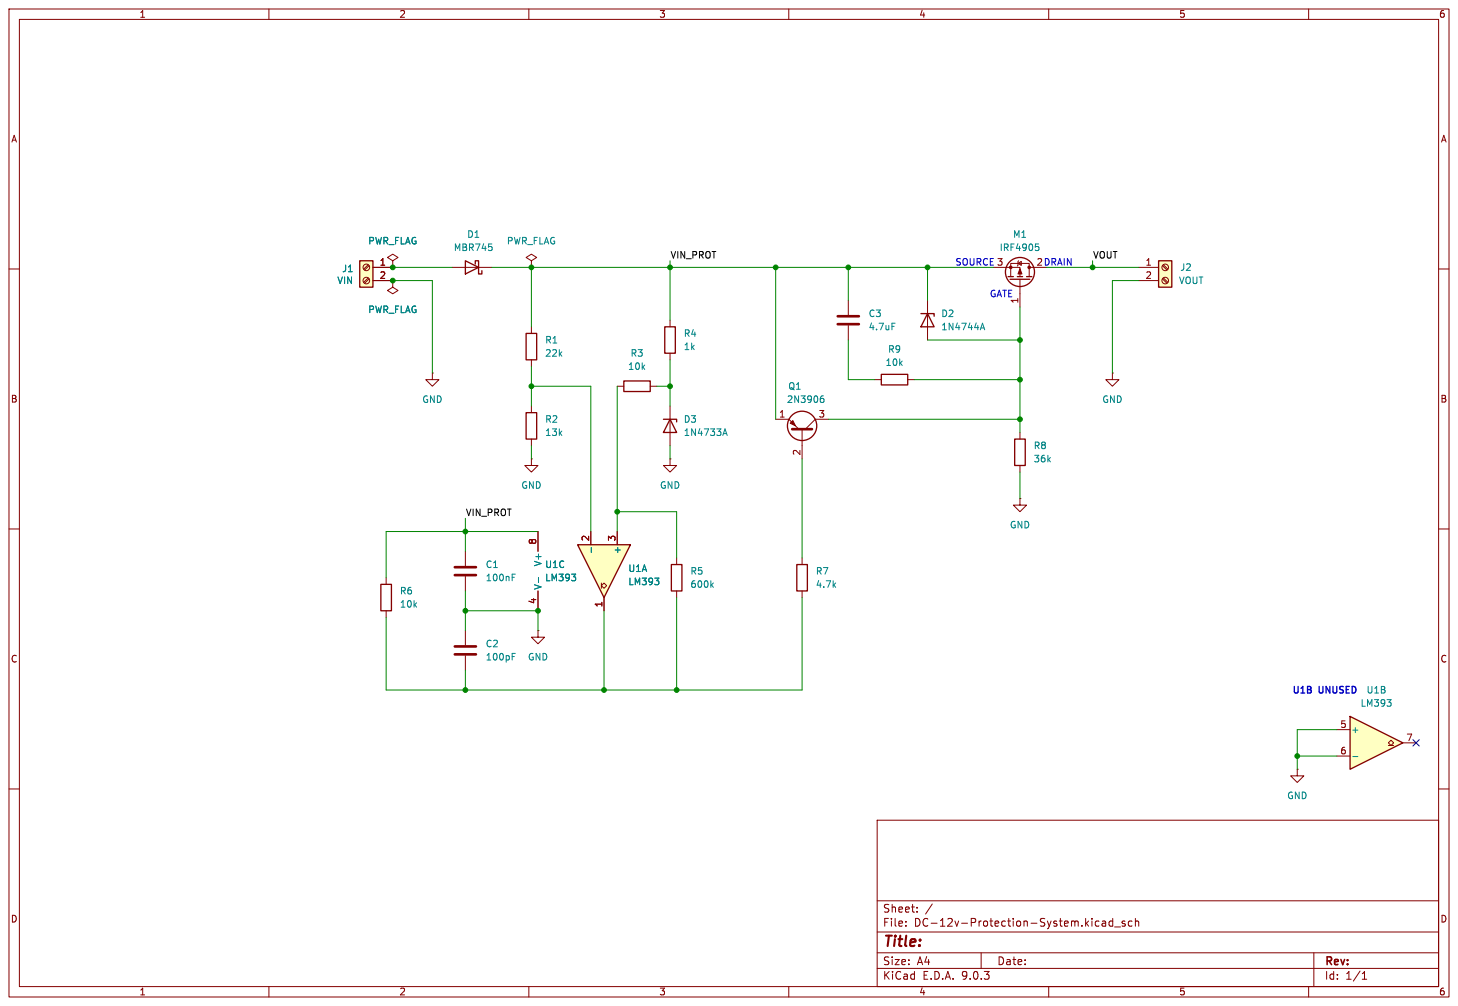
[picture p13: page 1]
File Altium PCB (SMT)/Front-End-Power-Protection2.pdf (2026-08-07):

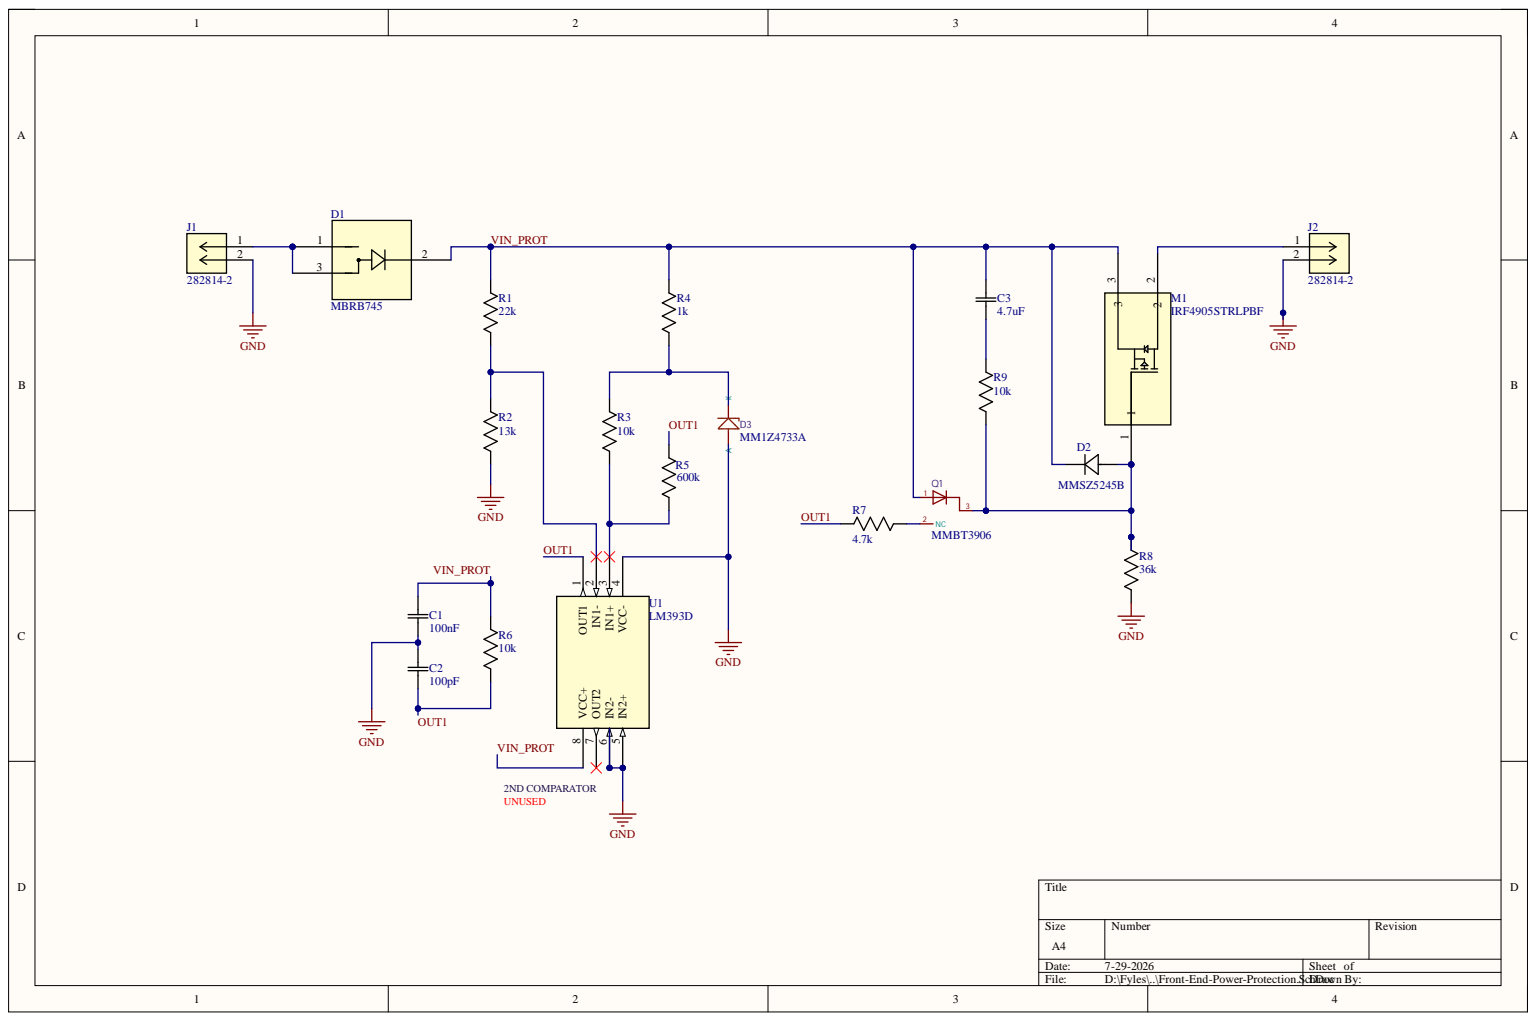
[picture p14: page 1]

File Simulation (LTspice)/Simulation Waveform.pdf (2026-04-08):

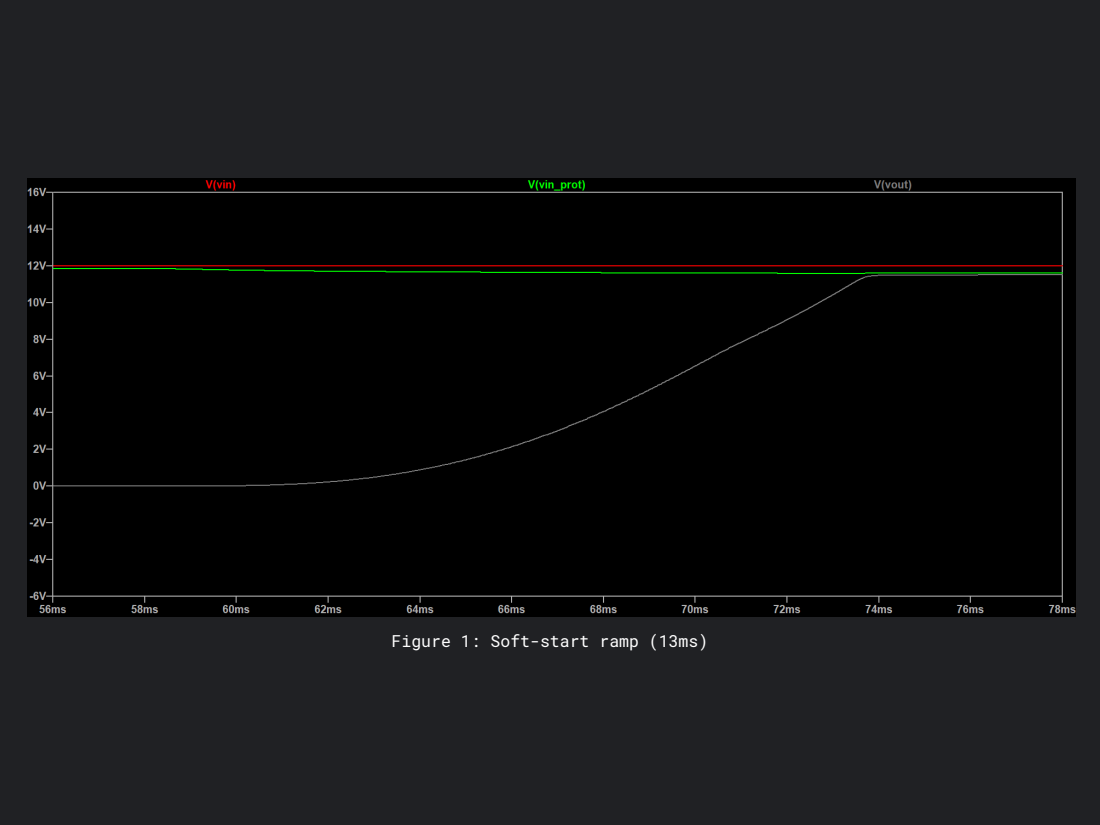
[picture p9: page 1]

Figure 1: Soft-start ramp (13ms)

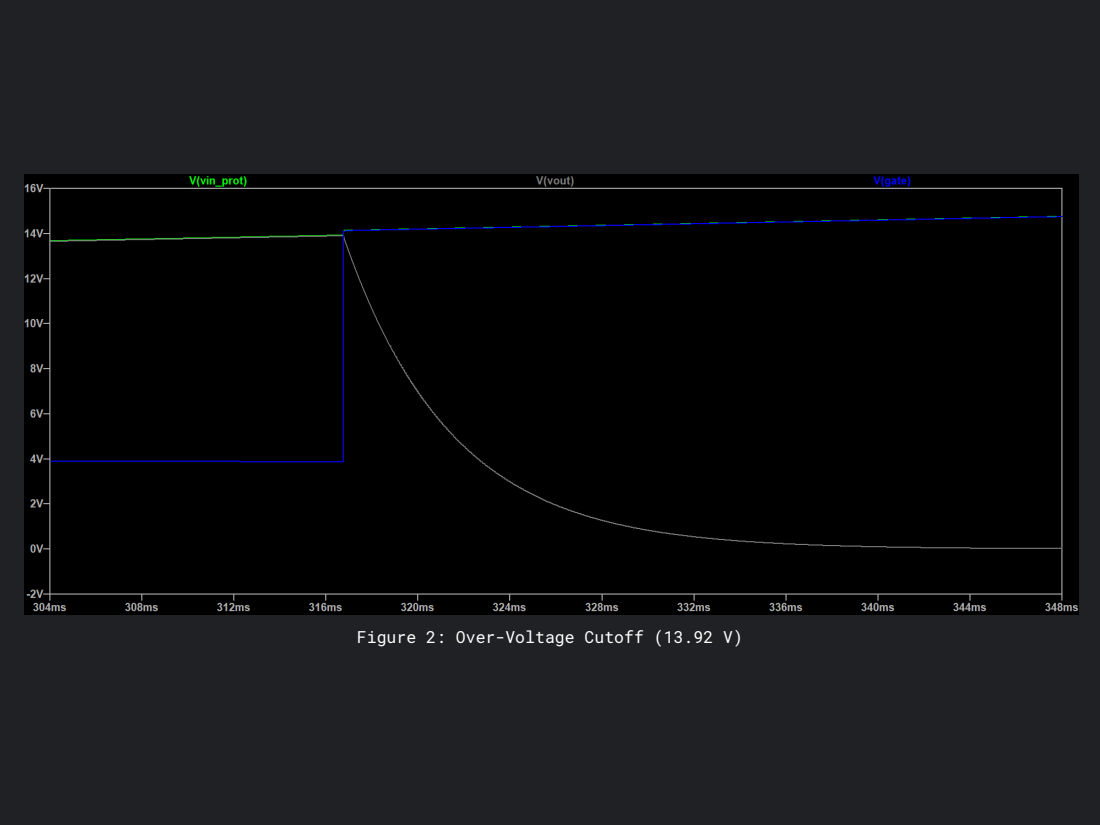
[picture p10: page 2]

Figure 2: Over-Voltage Cutoff (13.92 V)

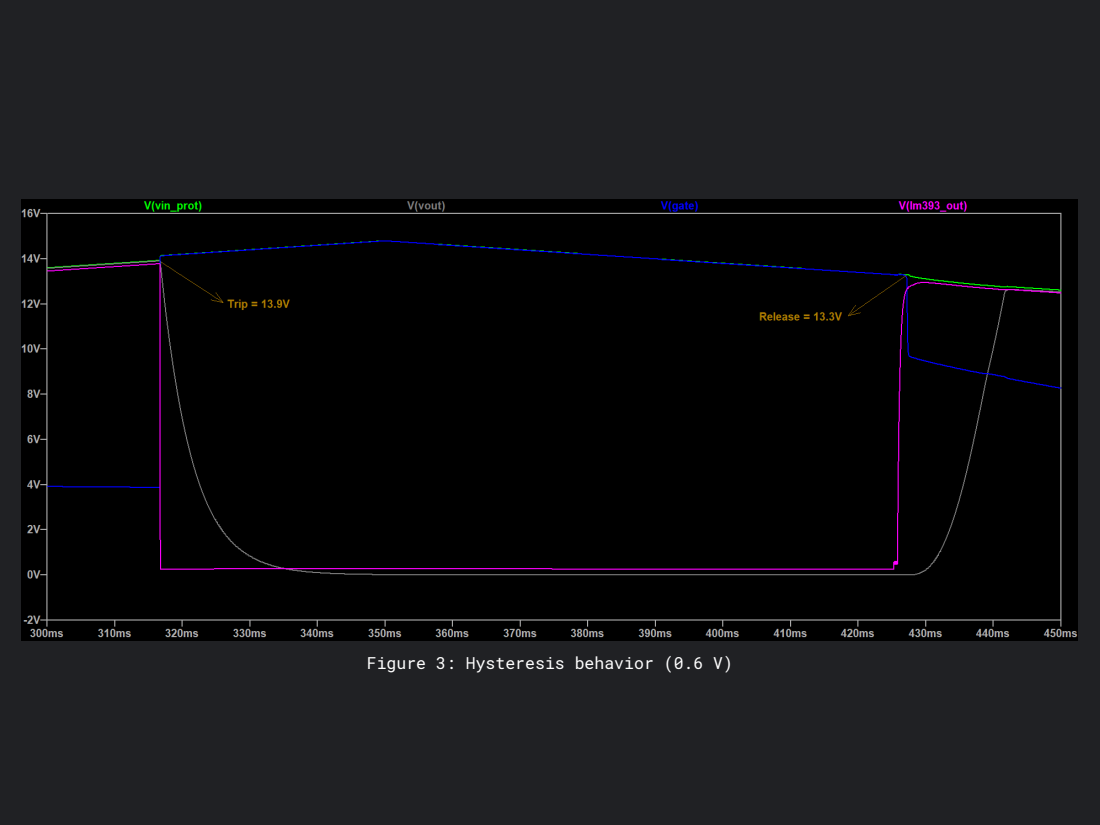
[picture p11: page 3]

Figure 3:Hysteresis behavior (0.6 V)

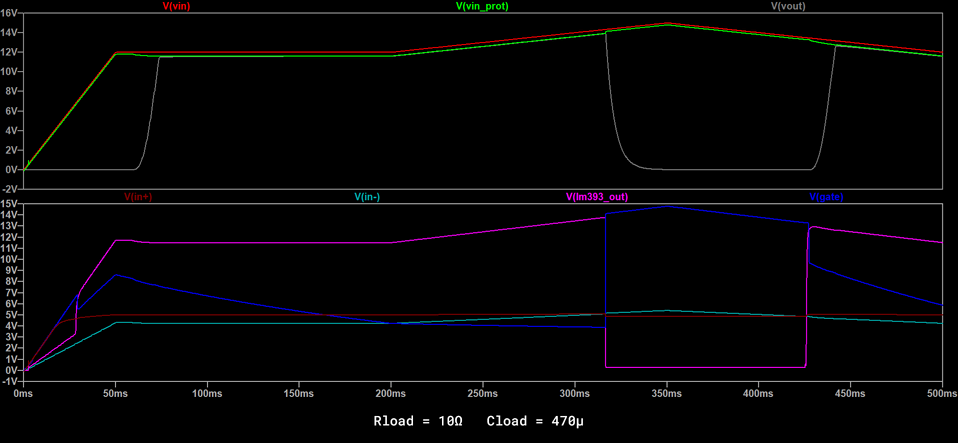
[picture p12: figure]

Figure 4:Full Waveform
